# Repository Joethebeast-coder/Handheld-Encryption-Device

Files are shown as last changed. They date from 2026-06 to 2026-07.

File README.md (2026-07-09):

# Handcryption

A hardware-based encrypted peer-to-peer messaging device built on **CircuitPython** (ESP32-S2), with a companion Flask server for speech-to-text, message relay, and group chat support.

---
## Pre-funding Images
___
### Shell Top
IMG_E3014

### Shell Bottom
IMG_E3015

---
## Final Images
___
### Shell Top
IMG_E3039

### Shell Bottom


___
## Table of Contents

- [Overview](#overview)
- [Hardware](#hardware)
- [Project Structure](#project-structure)
- [How It Works](#how-it-works)
  - [Wi-Fi Setup](#wi-fi-setup)
  - [Server Connection & Authentication](#server-connection--authentication)
  - [Encryption (Cencrypt)](#encryption-cencrypt)
  - [Voice Message Encryption (RSA)](#voice-message-encryption-rsa)
  - [Peer-to-Peer Messaging](#peer-to-peer-messaging)
  - [Group Chat](#group-chat)
  - [Speech-to-Text](#speech-to-text)
  - [Text & Voice Input](#text--voice-input)
- [Server Setup](#server-setup)
- [Device Setup](#device-setup)
- [UI & Navigation](#ui--navigation)
- [File Storage](#file-storage)
- [Credits](#credits)

---

## Overview

### [Video Overview (Pre-funding)](https://www.youtube.com/watch?v=kqKA_LZ2jB4)
### [Full Build Test](https://youtu.be/IIfR6bDeaTY)

Handcryption is a hardware-based encrypted peer-to-peer messaging device built around physical ESP32-S2 devices and a Flask server hosted on a Raspberry Pi 4, exposed publicly via a **Cloudflare tunnel**. Messages can be sent as transcribed text or as fully encrypted voice clips. Text is transcribed by a local Vosk speech-to-text model on the companion server (or typed directly on the device), encrypted using a custom substitution cipher (text) or an RSA-protected XOR cipher (voice), and relayed through the server's mailbox system. The device uses an e-ink display and physical buttons for all interaction — no smartphone or touchscreen required.

Each device is assigned a unique numeric ID on first boot, which is used to route messages and identify contacts. A secondary group chat feature allows multiple devices to post to a shared encrypted channel viewable in a basic web interface.

> **Note on the platform:** This project originally targeted MicroPython. It now runs on **CircuitPython** (tested on CircuitPython 10.x for the Feather ESP32-S2). Display output uses Adafruit's `adafruit_epd` library rather than a standalone MicroPython driver, and several standard-library gaps in CircuitPython (e.g. `random.shuffle`, `os.path`) are worked around in the device code.

---

## Hardware

| Component | Purpose |
|---|---|
| Adafruit ESP32-S2 Feather (CircuitPython) | Main controller |
| Adafruit 2.13" SSD1680 monochrome e-ink display (250×122) | UI output via SPI |
| MAX17048 fuel gauge (I2C) | Battery percentage reading |
| DAC output | Audio feedback chimes and voice message playback (via amplifier) |
| Analog microphone (ADC) | Voice recording at 16 kHz |
| 6× push buttons | Record, Send, Select, Up, Down, Shut Off |

**Pin assignments:**

| Pin | Function |
|-----|---|
| 5 | Record button |
| 15 | Send message button |
| 39 | Select button |
| 8 | Up button |
| 38 | Down button |
| 16 | Shut-off button |
| A0 | Speaker (PWM, via amplifier) |
| A1 | Microphone (ADC) |
| 4/3 | I2C SCL/SDA (MAX17048) |
| 36/35/37 | SPI SCK/MOSI/MISO (e-ink) |
| 12/6/13/9 | E-ink DC/Busy/CS/Reset |

###



---

## Project Structure

```
handcryption/
├── code.py              # ESP32-S2 CircuitPython firmware (device code)
├── settings.toml        # Server URL + auth token (see Device Setup)
├── server.py            # Flask server (STT + relay + group chat backend)
├── Cencrypt.py          # Custom substitution cipher (cipher/decipher)
├── font5x8.bin          # Bitmap font used by adafruit_epd text rendering
├── lib/
│   ├── adafruit_epd/    # E-ink display library
│   ├── adafruit_requests/
│   ├── adafruit_connection_manager/
│   └── adafruit_framebuf/
├── models/
│   └── vosk-model-small-en-us-0.15/   # Vosk offline STT model (server-side)
├── templates/
│   └── web_msg.html     # Group chat web interface (server-side)
├── wifi.json            # Known Wi-Fi networks (auto-created)
├── known_ids.json       # Per-device-ID shuffled alphabet store (auto-created)
├── contacts.json        # Contact name → device ID map (auto-created)
├── history.json         # Message log, sent and received (auto-created)
├── my_letters.json      # Client-side cipher alphabet (auto-created)
├── gc_username.json     # Group chat username (auto-created)
├── priv_keys.json       # RSA key material for voice message encryption (auto-created)
└── device_ID.json       # This device's unique ID (auto-created on first boot)
```

> On CircuitPython, the main firmware file is named `code.py` on the device. The libraries under `lib/` come from the Adafruit CircuitPython library bundle.

---

## How It Works

### Wi-Fi Setup

On first boot (or if no known network is reachable), the device prompts the user to record a Wi-Fi name and password by voice. Since voice-to-text transcription of network credentials is error-prone, the device provides a character-by-character editor:

- **Up** — capitalize the current letter
- **Down** — lowercase the current letter
- **Select** — move to the next letter
- **Send** — toggle the current word between digit and word form (e.g., "five" ↔ "5"), useful for fixing numbers misheard as words

Once confirmed, the SSID/password pair is appended to a list in `wifi.json`. On every subsequent boot, the device tries each known network in order; if none connect within the timeout, it prompts for a new network and adds it to the list.

### Server Connection & Authentication

The device does not hardcode a server address. Instead, the server URL and a shared authentication token are read from `settings.toml`:

```
SERVER_URL = "https://your-endpoint.example.com"
DEVICE_TOKEN = "your-long-random-shared-secret"
```

All requests to the server include an `X-Auth` header carrying the token, and the Flask server rejects any request without the matching token (HTTP 401). This keeps the publicly reachable endpoint from being driven by anyone who discovers the URL.

Because the server is reached over an outbound tunnel, the device works from any network with internet access — the Raspberry Pi does not need port forwarding or a static public IP.

### Encryption (Cencrypt)

Handcryption uses [Cencrypt](https://pypi.org/project/Cencrypt/), a custom substitution cipher library available on PyPI, for text messages. The full printable character set (letters, digits, punctuation, space) is stored in `LETTERS`. When two devices connect for the first time, the sending device shuffles a copy of `LETTERS` and sends it to the recipient via the server mailbox as that device's personal cipher alphabet. This shuffled alphabet is saved to `known_ids.json` on the sender and `my_letters.json` on the recipient, so future sessions reuse the same key.

- `Cencrypt.cipher(message, alphabet)` — encrypts a plaintext string using the shuffled alphabet; returns the ciphertext and the key used for that message.
- `Cencrypt.decipher(ciphertext, alphabet)` — decrypts a message given the matching alphabet.

The combined message sent over the wire is `key + ciphertext` concatenated into a single string.

> **Note:** CircuitPython's `random` module has no `shuffle()`, so the device implements a Fisher–Yates shuffle internally to build cipher alphabets.

### Voice Message Encryption (RSA)

Voice messages use a separate encryption scheme since the substitution cipher only operates on text. Each device generates a 2048-bit RSA keypair on first boot (the server generates the large primes, since this is too slow on the microcontroller itself) and publishes its public key to the server. The public key is re-published on every boot, so a failed first-boot upload self-heals on the next start.

To send a voice message:
1. A random XOR key is generated locally.
2. The recorded PCM audio is XOR-encrypted with that key.
3. The XOR key itself is encrypted using the recipient's RSA public key (fetched from the server via `get_cont_pub_key`).
4. The encrypted key and encrypted audio are concatenated, base64-encoded, and sent through the mailbox with `"type": "audio"`.

On receipt, the recipient decrypts the XOR key using its own RSA private key, then XOR-decrypts the audio and plays it back through the speaker. If no public key is on file for the target contact, the device reports this instead of failing.

> **Note:** Audio messaging is the most fragile feature of the device. Because capture relies on a simple analog microphone (sampled directly through the ADC, with no dedicated audio codec or noise handling), recordings are prone to noise, clipping, and inconsistent levels. This affects both voice messages and speech-to-text accuracy. Text input (typed or transcribed) is the more reliable path; treat voice messages as best-effort.

### Peer-to-Peer Messaging

Messaging is relayed through the Flask server's mailbox system rather than direct socket connections. Each device has a unique 9-digit numeric ID assigned at first boot.

**Sending** (`esp_network_server`):
1. If the target device ID is new, prompts the user to name the contact (by voice or by typing), generates a shuffled cipher alphabet, and delivers it to the recipient via `POST /send-msg` with `"type": "key_exchange"`.
2. Saves the shuffled alphabet to `known_ids.json` keyed by the target's device ID. (Because JSON object keys are strings, device IDs are handled as strings for these lookups.)
3. For text messages: encrypts the outbound message using the stored alphabet for that contact and posts it with `"type": "txt"`.
4. For voice messages: encrypts the recorded audio using RSA as described above and posts it with `"type": "audio"`.
5. Saves the exchange to `history.json`.

**Receiving** (`esp_network_client`):
1. On entering receive mode, polls `GET /updates?Request=check_mail&dev_id=<id>` for new messages. Press **Record** to leave receive mode and return to the menu.
2. Messages are dispatched by type:
   - `"key_exchange"` — saves the received alphabet to `my_letters.json`.
   - `"txt"` — deciphers using the stored alphabet, plays a notification chime, displays the message, and logs it to `history.json`.
   - `"audio"` — decrypts the RSA-protected audio and plays it back.

### Group Chat

The group chat feature routes through the Flask server:

1. The user sets a username on first use (by voice or typing, persisted to `gc_username.json` so it only needs to be set once).
2. Messages are posted via `POST /gc` with the username, device ID, and message as parameters.
3. The server encrypts incoming messages with a single server-side shuffled alphabet (`ALPH`) and appends them to `messg_hist`.
4. Devices retrieve the server alphabet via `GET /updates?Request=serv_letters` and message history via `GET /updates?Request=prov_hist`, then decrypt locally with `Cencrypt.decipher`.
5. The web interface at `/gc` (served by `web_msg.html`) polls `GET /messages` every 2 seconds and renders the encrypted message log in a browser — messages appear encrypted to anyone intercepting the HTTP traffic.

### Speech-to-Text

Audio is captured at **16 kHz** mono using the ADC. While the record button is held, 16-bit PCM samples are collected in memory. On release, a WAV file is written to flash (`recording.wav`) and uploaded via `POST /stt` to the Flask server, along with the device's ID.

The server processes the audio with **Vosk** (offline STT, no cloud dependency) using `vosk-model-small-en-us-0.15`. The transcribed text is returned as JSON and displayed on screen for confirmation before use. A simple filler-word filter (`processing()`) strips common hesitation words (`"uh"`, `"um"`, `"hmm"`, etc.) from the result.

> The recording sample rate (16 kHz) matches the rate the Vosk model expects. Recording at a mismatched rate (e.g. 8 kHz) causes the server to reject the audio.

### Text & Voice Input

Anywhere the device asks for input — contact names, contact IDs, message text, and group chat — you can either **record by voice** or **type on the device**:

- At a record prompt, press **Up** to switch to the on-screen text editor instead of recording.
- In the text editor: **Up/Down** scroll through characters, **Select** commits the current character, **Record** (tap) is backspace, **Record** (hold ~1s) exits, and **Send** finishes.

This makes the device usable even when speech-to-text is unavailable or inaccurate.

---

## Server Setup

### Requirements

```bash
pip install flask waitress vosk Cencrypt pycryptodome
```

Download the Vosk model and place it at `models/vosk-model-small-en-us-0.15/`:
```
https://alphacephei.com/vosk/models
```

You will also need a way to expose the server publicly. This project uses a **Cloudflare tunnel** (`cloudflared`) running on the Raspberry Pi, which requires no port forwarding and works behind CGNAT.

### Authentication token

The server reads a shared secret from the `DEVICE_TOKEN` environment variable and rejects any request whose `X-Auth` header does not match. Set the same value here and in each device's `settings.toml`.

### Running

Run the Flask app under a production server (Waitress) so it survives long-running use:

```bash
DEVICE_TOKEN=your-long-random-shared-secret \
  waitress-serve --port=5000 server:app
```

In a separate terminal (or as a service), start the tunnel:

```bash
cloudflared tunnel --url http://localhost:5000
```

`cloudflared` prints a public HTTPS URL. Put that URL in each device's `settings.toml` as `SERVER_URL`. For a permanent address that survives restarts, use a **named** Cloudflare tunnel with your own domain instead of the quick-tunnel URL.

> For an always-on setup, run both the Flask server and `cloudflared` as `systemd` services so they restart on boot.

### Endpoints

All endpoints require the `X-Auth` header.

| Method | Route | Description |
|---|---|---|
| `POST` | `/stt` | Accepts a WAV file + device ID, returns `{"text": "..."}` |
| `GET` | `/messages` | Returns full encrypted group chat message history as JSON (polled by the web UI) |
| `GET/POST` | `/gc` | Post a group chat message or view the web UI |
| `GET/POST` | `/updates` | Returns server alphabet, group chat history, mailbox contents, RSA public keys, or stores a public key, depending on `Request` |
| `GET/POST` | `/getID` | Registers a new device ID; returns `"Clear"` if available or a new unique ID |
| `GET/POST` | `/send-msg` | Deposits a message (text, audio, or key exchange) into a device's mailbox by destination ID |
| `GET/POST` | `/get_prime` | Generates a 2048-bit RSA keypair's components for a requesting device |

---

## Device Setup

1. Flash **CircuitPython** to the ESP32-S2 Feather.
2. Copy the required libraries into `lib/` from the Adafruit CircuitPython library bundle: `adafruit_epd`, `adafruit_requests`, `adafruit_connection_manager`, and `adafruit_framebuf`. Also copy `font5x8.bin` to the drive root (used for text rendering).
3. Upload `code.py` (the device firmware), `Cencrypt.py`, and the `settings.toml` file to the device. `Cencrypt.py` can be downloaded from [PyPI](https://pypi.org/project/Cencrypt/).
4. Edit `settings.toml` with your server URL and token:
   ```
   SERVER_URL = "https://your-endpoint.example.com"
   DEVICE_TOKEN = "your-long-random-shared-secret"
   ```
5. Power on — on first boot, the device will prompt you to record or type a Wi-Fi network name and password (see [Wi-Fi Setup](#wi-fi-setup)).
6. After connecting, the device displays "HANDCRYPTION", plays the startup chime, registers its device ID with the server, generates its RSA keypair for voice messages, and publishes its public key.

---

## UI & Navigation

The main menu has four icon options navigated with **Up/Down** and confirmed with **Select**. The currently highlighted option is drawn with a border box.

| Icon | Option | Action |
|---|---|---|
| History | `0` | Browse past messages (sent and received) |
| Contacts | `1` | View or add contacts |
| Settings | `2` | Reset data or adjust volume |
| Message bubble | `3` | Access group chat |
| *(Send button)* | `4` | Send a direct message — choose text or voice |
| *(Idle timeout)* | `5` | Enter receive mode |

When sending a direct message (`4`), the device asks whether to send as **text** (Up) or **voice** (Down). Text messages go through the record-or-type → (transcribe) → confirm flow. Voice messages are recorded, encrypted with the recipient's RSA public key, and sent as raw encrypted audio without transcription.

**Button reference:**

| Button | Role |
|---|---|
| Record | Capture audio (hold); in the text editor, tap = backspace, hold = exit; also "go back" in some screens |
| Send | Open send-message flow / confirm in text editor |
| Select | Confirm selection / commit character in text editor |
| Up / Down | Navigate menus and characters; Up also switches a record prompt to typing |
| Shut Off (hold 1s+) | Deep sleep (wakes on next power press) |

**Display note:** The e-ink panel performs full refreshes only. The UI is designed to refresh once per screen change rather than continuously, so navigation updates when a selection changes rather than animating.

**Battery** is drawn as a small icon in the top-right corner of every screen. The device shows a charging prompt if battery drops below 45% and blocks until it reaches 60%.

**Audio feedback chimes:**
- `wake_chime` — on screen wake
- `handcryption_chime` — on startup
- `notif_chime` — on message received
- `shut_off_chime` — on entering deep sleep

---

## File Storage

All JSON files are created automatically on first boot if absent.

| File | Contents |
|---|---|
| `settings.toml` | `SERVER_URL` and `DEVICE_TOKEN` (server address + auth secret) |
| `wifi.json` | Array of known Wi-Fi networks as `[ssid, password]` pairs, tried in order on boot |
| `device_ID.json` | This device's unique 9-digit ID, registered with the server on first boot |
| `gc_username.json` | The username used for group chat, set on first use of that feature |
| `priv_keys.json` | RSA key material (`phi/d/n/key1/key2`) used for encrypting/decrypting voice messages |
| `known_ids.json` | `{ "device_id": [shuffled alphabet array], ... }` (keys stored as strings) |
| `contacts.json` | `{ "Name": "device_id", ... }` |
| `history.json` | Array of message records; sent entries carry a `To` field, received entries carry a `From` field |
| `my_letters.json` | Cipher alphabet received from sender (used in receive mode) |
| `recording.wav` | Temporary audio file, overwritten on each recording |

The **Settings → Reset** option wipes `contacts.json`, `history.json`, and `known_ids.json` back to empty — forcing a full re-handshake and new cipher key exchange on the next connection.

---

## Credits

This project began as a MicroPython build and was ported to **CircuitPython**. The e-ink display now uses Adafruit's [`adafruit_epd`](https://github.com/adafruit/Adafruit_CircuitPython_EPD) library.

The original MicroPython SSD1680 display driver and font work that inspired the earlier version of this project were based on work by [hfwang132](https://github.com/hfwang132), available at [hfwang132/ssd1680-micropython-drivers](https://github.com/hfwang132/ssd1680-micropython-drivers/tree/main). Many thanks for the MicroPython driver that made the display portion of the original project possible.

## AI Usage

AI was used to help find and fix bugs in the code, mainly when I converted the project from MicroPython to CircuitPython.

---

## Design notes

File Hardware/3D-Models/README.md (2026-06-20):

This is the folder for all 3D-Models. Note that many of the part measurements for height are estimates. The assembly does not show the standoffs and screws.

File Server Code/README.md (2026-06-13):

Quick Overview
---------------------------------------------------------
This is the server code that will run on a Raspberry Pi 4

How it works
----------------------------------------------------------------
It uses Flask to create an HTTP server where the microcontroller
can make requests.

Types of Requests
    1. Speech-to-text
        The microcontroller cannot run the speech-to-text API on its own, so it makes
        a request to the server to convert an audio file.
    2. Group Chat
        The microcontroller can connect to a group chat that is between every user. This
        section allows the microcontroller to send messages in the group chat
    3. Updates
        The microcontroller can request updates from the server, such as the server's set of letters
        used to encrypt the messages of the group chat, as well as its message history.

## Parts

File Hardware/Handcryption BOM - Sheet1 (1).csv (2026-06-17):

Item | ID | Quantity | Cost | Total Item Cost | Vendor
Adafruit 2.13" Monochrome eInk / ePaper Display with SRAM - 250x122 Monochrome with SSD1680 | 4197 | 2 | $22.50 | $45.00 | Adafruit
Tactile Button switch (6mm) x 20 pack | 367 | 1 | $2.50 | $2.50 | Adafruit
Adafruit ESP32-S2 Feather - 4 MB Flash + 2 MB PSRAM - STEMMA QT / Qwiic | 5000 | 2 | $17.50 | $35.00 | Adafruit | Total | $128.94
Lithium Ion Polymer Battery - 3.7v 100mAh | 1570 | 2 | $11.90 | $23.80 | Adafruit
6 Pieces Electret Microphone Amplifier Module MAX4466 Adjustable Gain | B08N4FNFTR | 1 | $9.99 | $9.99 | Amazon
Adafruit STEMMA Speaker - Plug and Play Audio Amplifier - JST PH 2mm | 3885 | 2 | $5.95 | $11.90 | Adafruit
JST PH 2mm 3-pin Plug-Plug Cable - 100mm long | 4336 | 1 | $0.75 | $0.75 | Adafruit
 |  |  |  | $0.00
 |  |  |  | $0.00
 |  |  |  | $0.00
 |  |  |  | $0.00
 |  |  |  | $0.00
 |  |  |  | $0.00
 |  |  |  | $0.00
 |  |  |  | $0.00
 |  |  |  | $0.00
 |  |  |  | $0.00
 |  |  |  | $0.00
 |  |  |  | $0.00
 |  |  |  | $0.00
 |  |  |  | $0.00
 |  |  |  | $0.00
 |  |  |  | $0.00
 |  |  |  | $0.00
 |  |  |  | $0.00
 |  |  |  | $0.00
 |  |  |  | $0.00
 |  |  |  | $0.00
 |  |  |  | $0.00
 |  |  |  | $0.00
 |  |  |  | $0.00
 |  |  |  | $0.00
 |  |  |  | $0.00
 |  |  |  | $0.00
 |  |  |  | $0.00
 |  |  |  | $0.00
 |  |  |  | $0.00
 |  |  |  | $0.00
 |  |  |  | $0.00
 |  |  |  | $0.00
 |  |  |  | $0.00
 |  |  |  | $0.00
 |  |  |  | $0.00
 |  |  |  | $0.00
 |  |  |  | $0.00
 |  |  |  | $0.00
 |  |  |  | $0.00
 |  |  |  | $0.00
 |  |  |  | $0.00
 |  |  |  | $0.00
 |  |  |  | $0.00
 |  |  |  | $0.00
 |  |  |  | $0.00
 |  |  |  | $0.00
 |  |  |  | $0.00
 |  |  |  | $0.00
 |  |  |  | $0.00
 |  |  |  | $0.00
 |  |  |  | $0.00
 |  |  |  | $0.00
 |  |  |  | $0.00
 |  |  |  | $0.00
 |  |  |  | $0.00
 |  |  |  | $0.00
 |  |  |  | $0.00
 |  |  |  | $0.00
 |  |  |  | $0.00
 |  |  |  | $0.00
 |  |  |  | $0.00
 |  |  |  | $0.00
 |  |  |  | $0.00
 |  |  |  | $0.00
 |  |  |  | $0.00
 |  |  |  | $0.00
 |  |  |  | $0.00
 |  |  |  | $0.00
 |  |  |  | $0.00
 |  |  |  | $0.00
 |  |  |  | $0.00
 |  |  |  | $0.00
 |  |  |  | $0.00
 |  |  |  | $0.00
 |  |  |  | $0.00
 |  |  |  | $0.00
 |  |  |  | $0.00
 |  |  |  | $0.00
 |  |  |  | $0.00
 |  |  |  | $0.00
 |  |  |  | $0.00
 |  |  |  | $0.00
 |  |  |  | $0.00
 |  |  |  | $0.00
 |  |  |  | $0.00
 |  |  |  | $0.00
 |  |  |  | $0.00
 |  |  |  | $0.00
 |  |  |  | $0.00
 |  |  |  | $0.00
 |  |  |  | $0.00
 |  |  |  | $0.00
 |  |  |  | $0.00
 |  |  |  | $0.00
 |  |  |  | $0.00
 |  |  |  | $0.00
 |  |  |  | $0.00
 |  |  |  | $0.00
 |  |  |  | $0.00
 |  |  |  | $0.00
 |  |  |  | $0.00
 |  |  |  | $0.00
 |  |  |  | $0.00
 |  |  |  | $0.00
 |  |  |  | $0.00
 |  |  |  | $0.00
 |  |  |  | $0.00
 |  |  |  | $0.00
 |  |  |  | $0.00
 |  |  |  | $0.00
 |  |  |  | $0.00
 |  |  |  | $0.00
 |  |  |  | $0.00
 |  |  |  | $0.00
 |  |  |  | $0.00
 |  |  |  | $0.00
 |  |  |  | $0.00
 |  |  |  | $0.00
 |  |  |  | $0.00
 |  |  |  | $0.00
 |  |  |  | $0.00
 |  |  |  | $0.00
 |  |  |  | $0.00
 |  |  |  | $0.00
 |  |  |  | $0.00
 |  |  |  | $0.00
 |  |  |  | $0.00
 |  |  |  | $0.00
 |  |  |  | $0.00
 |  |  |  | $0.00
 |  |  |  | $0.00
 |  |  |  | $0.00
 |  |  |  | $0.00
 |  |  |  | $0.00
 |  |  |  | $0.00
 |  |  |  | $0.00
 |  |  |  | $0.00
 |  |  |  | $0.00
 |  |  |  | $0.00
 |  |  |  | $0.00
 |  |  |  | $0.00
 |  |  |  | $0.00
 |  |  |  | $0.00
 |  |  |  | $0.00
 |  |  |  | $0.00
 |  |  |  | $0.00
 |  |  |  | $0.00
 |  |  |  | $0.00
 |  |  |  | $0.00
 |  |  |  | $0.00
 |  |  |  | $0.00
 |  |  |  | $0.00
 |  |  |  | $0.00
 |  |  |  | $0.00
 |  |  |  | $0.00
 |  |  |  | $0.00
 |  |  |  | $0.00
 |  |  |  | $0.00
 |  |  |  | $0.00
 |  |  |  | $0.00
 |  |  |  | $0.00
 |  |  |  | $0.00
 |  |  |  | $0.00
 |  |  |  | $0.00
 |  |  |  | $0.00
 |  |  |  | $0.00
 |  |  |  | $0.00
 |  |  |  | $0.00
 |  |  |  | $0.00
 |  |  |  | $0.00
 |  |  |  | $0.00
 |  |  |  | $0.00
 |  |  |  | $0.00
 |  |  |  | $0.00
 |  |  |  | $0.00

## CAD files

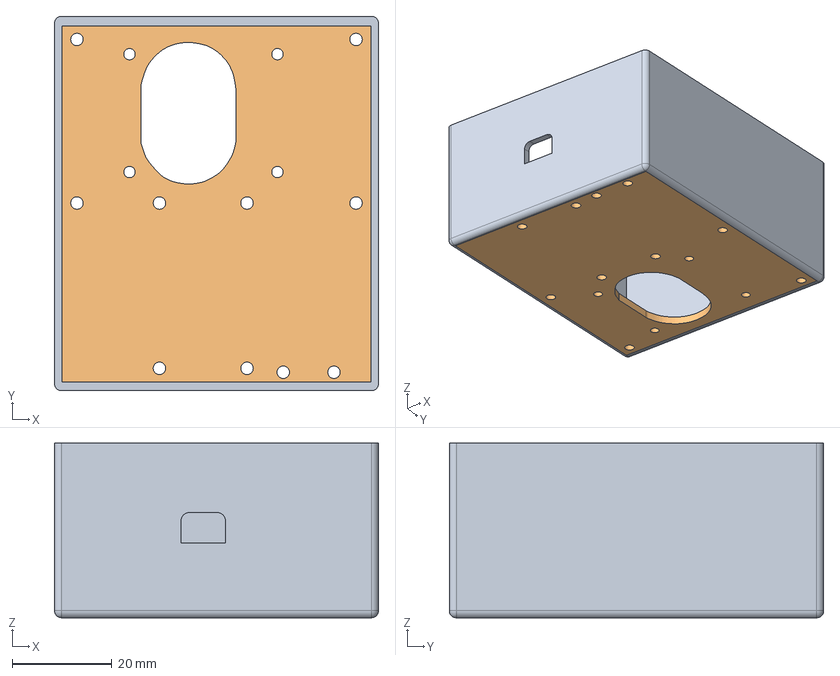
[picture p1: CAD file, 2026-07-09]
Hardware/3D-Models/Main Body.step
65.0 x 75.1 x 35.0 mm

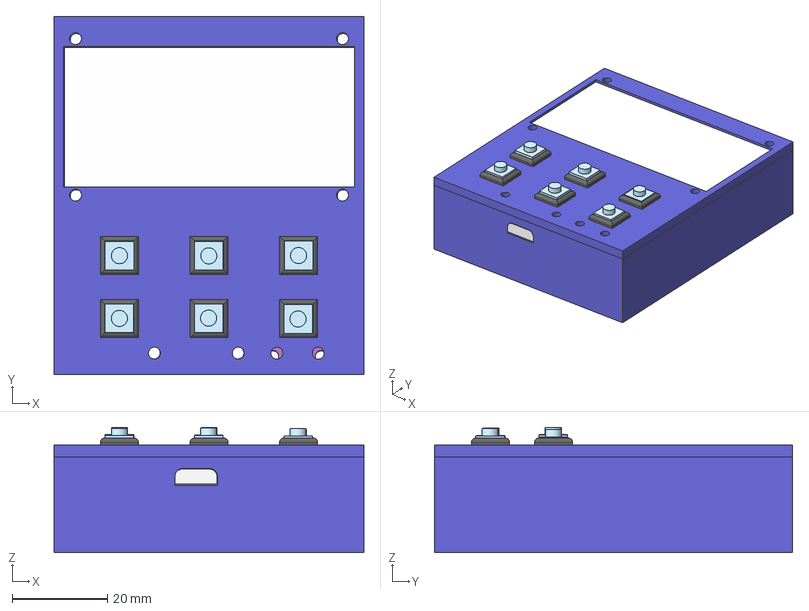
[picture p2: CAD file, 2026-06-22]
Hardware/3D-Models/Assembly 1.step
65.0 x 75.1 x 26.3 mm

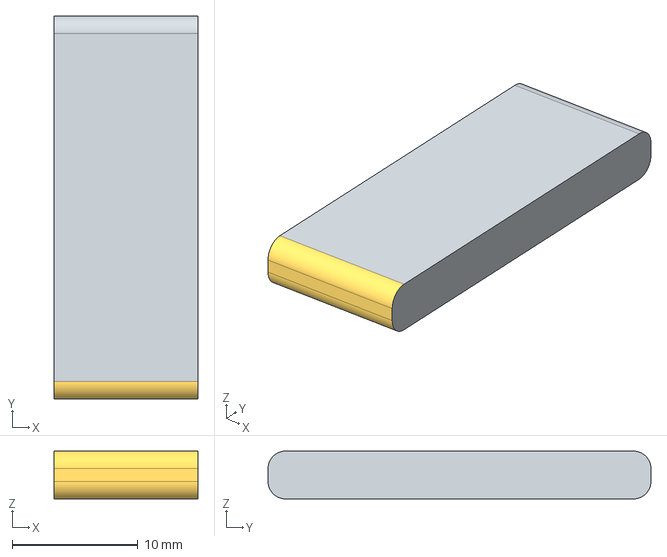
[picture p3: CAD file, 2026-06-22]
Hardware/3D-Models/Battery.step
11.4 x 30.5 x 3.81 mm

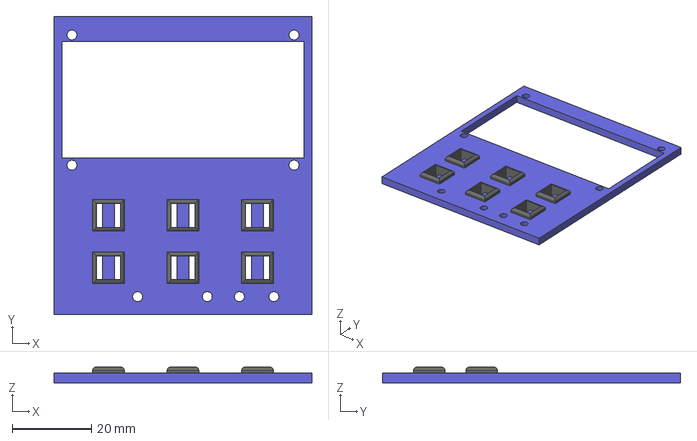
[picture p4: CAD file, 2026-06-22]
Hardware/3D-Models/Top Cover.step
65.0 x 75.1 x 4.00 mm

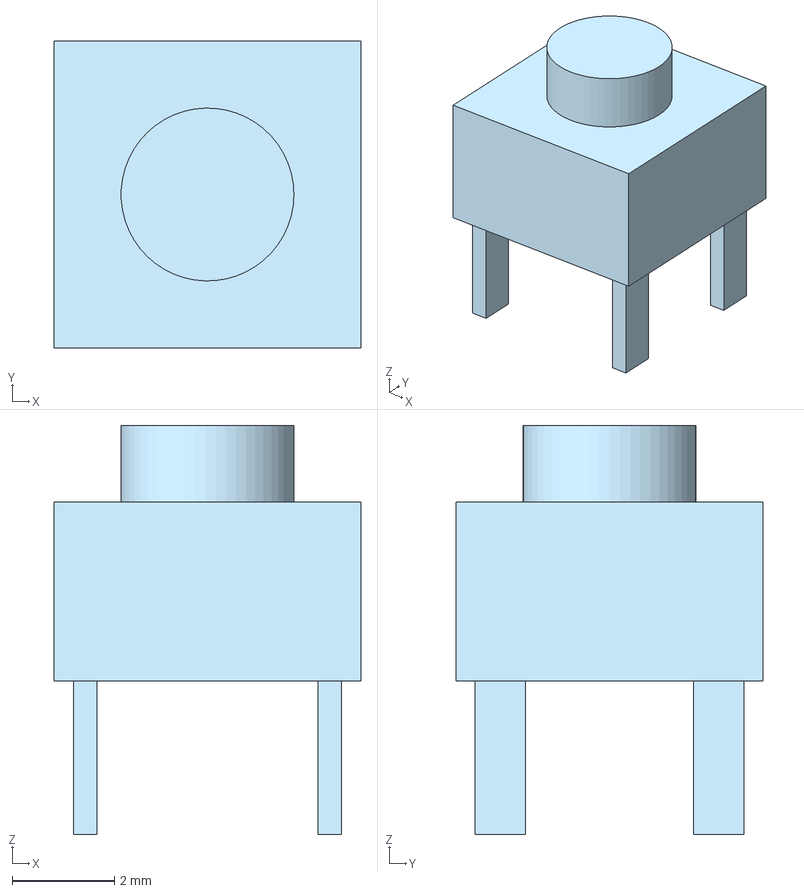
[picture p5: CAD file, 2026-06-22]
Hardware/3D-Models/Button.step
6.00 x 6.00 x 8.00 mm

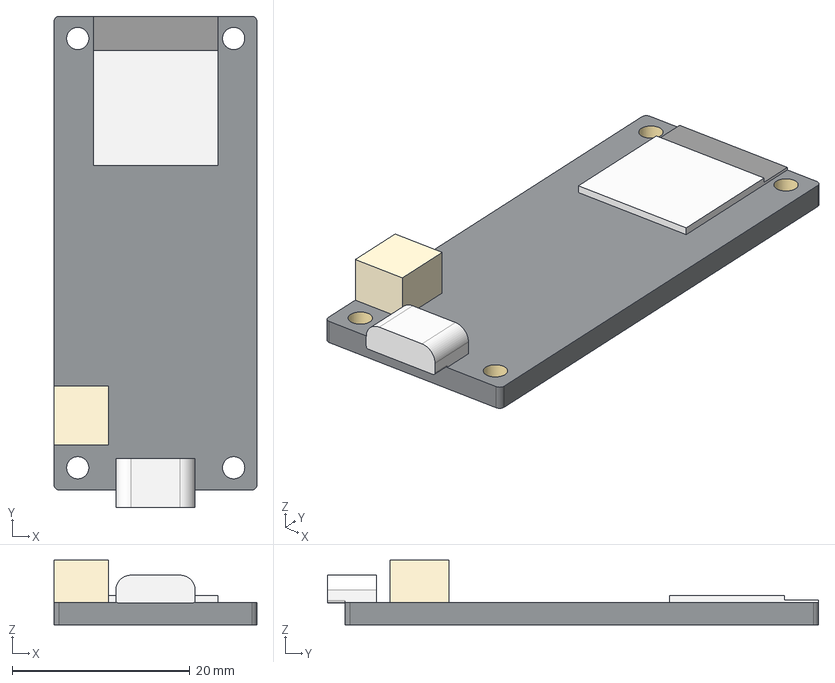
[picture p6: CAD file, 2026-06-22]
Hardware/3D-Models/Adafruit ESP32-S2 Feather Board.step
22.9 x 55.3 x 7.30 mm

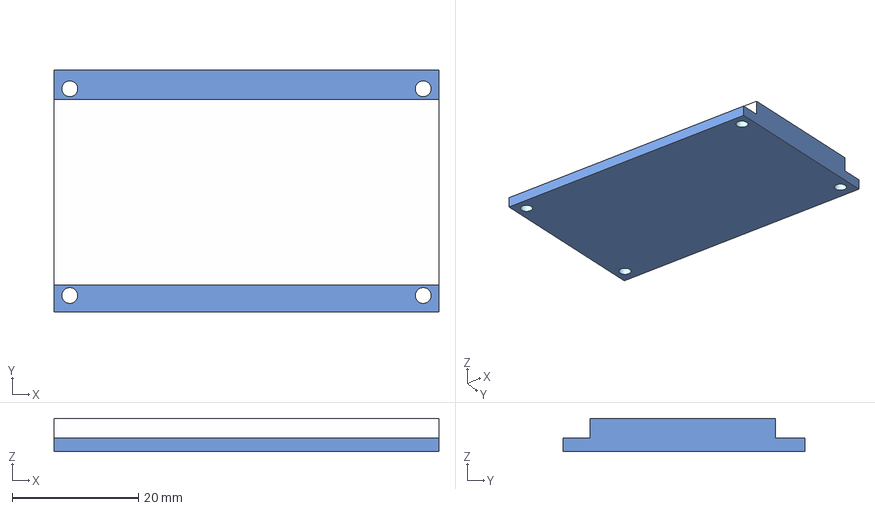
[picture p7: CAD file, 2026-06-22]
Hardware/3D-Models/Adafruit 2.13- Monochrome eInk - ePaper Display.step
61.0 x 38.3 x 5.30 mm

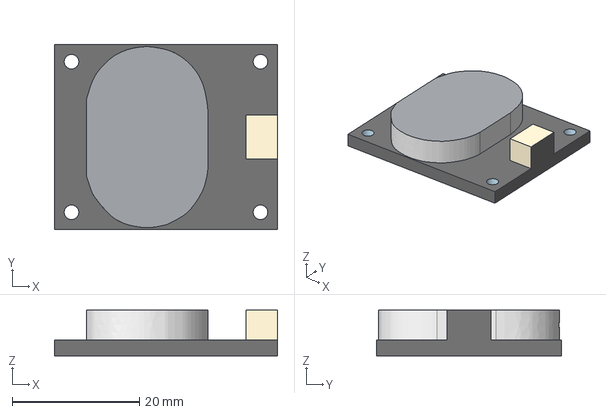
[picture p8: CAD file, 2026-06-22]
Hardware/3D-Models/Adafruit STEMMA Speaker.step
35.0 x 29.0 x 7.20 mm

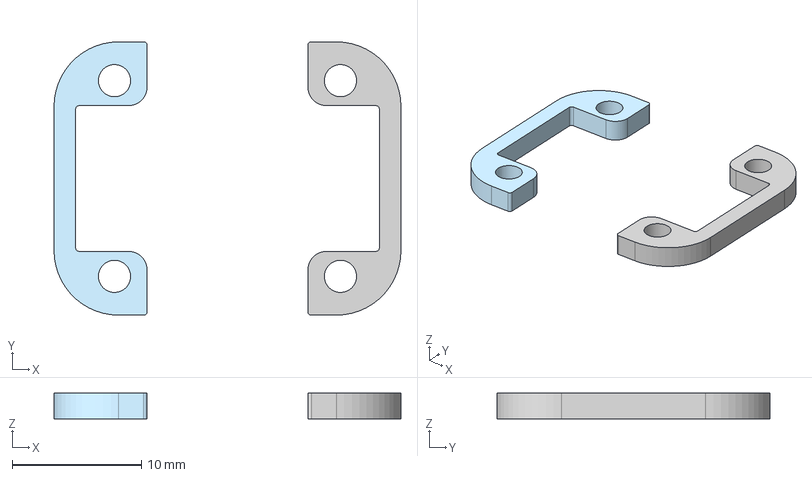
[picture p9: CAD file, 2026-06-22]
Hardware/3D-Models/Board Holders.step
26.8 x 21.1 x 2.00 mm

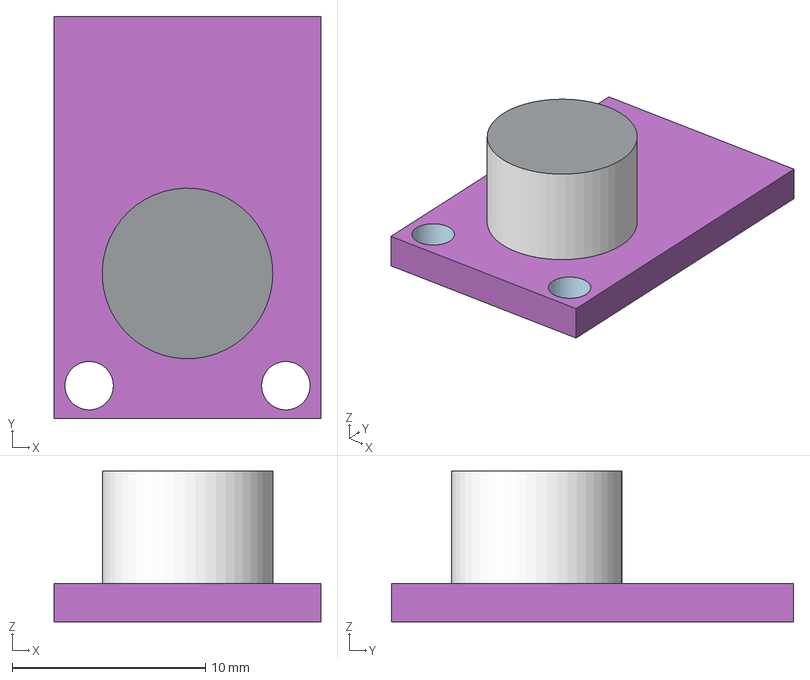
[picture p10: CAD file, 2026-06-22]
Hardware/3D-Models/Electret Microphone Amplifier Module MAX4466.step
13.8 x 20.8 x 7.80 mm

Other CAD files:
Hardware/3D-Models/Main Body (3).stl
Hardware/3D-Models/Adafruit 2.13- Monochrome eInk - ePaper Display.stl
Hardware/3D-Models/Adafruit ESP32-S2 Feather Board.stl
Hardware/3D-Models/Adafruit STEMMA Speaker.stl
Hardware/3D-Models/Assembly 1.stl
Hardware/3D-Models/Battery.stl
Hardware/3D-Models/Board Holders.stl
Hardware/3D-Models/Button.stl
Hardware/3D-Models/Electret Microphone Amplifier Module MAX4466.stl
Hardware/3D-Models/Top Cover.stl

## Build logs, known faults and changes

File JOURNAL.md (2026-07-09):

# Logs

## Hancryption Status Update 0.0.1
---------------------------------------
I have created the basic logic framework for the speech-to-text with processing. I am currently using many placeholders, however. Will be updating that by 0.0.4 at the latest. For encryption, I am using my previously developed “Cencrypt” Python library.
_____
### What’s Next in 0.0.2?
___
- Networking Framework
- Encryption Setup



#

## Handcryption Status Update 0.0.1.5
---
### What’s New?
____
I created a rough sketch of the device. I also wrote down a tentative list of parts I would need. See Below
0.0.2 Should be released by 6/4/26.
___
*Note: I completely forgot about the screen and the parts needed for that.
E-ink display
6 buttons



#

## Hancryption Status Update 0.0.2
---
### What Happened?
___
I added classes for server and client communication so the device could be either. I also added the encryption feature, which generates a unique key for each known IP address. The network also includes a client status check that occurs every 15 seconds, in which the client sends its IP address to the server.
___
### What’s Next in 0.0.3?
___
- Full draft code for a device. This will include all of the machine programming for the ESP32 chip, which is for the microphone, eink screen, and buttons.

- By 0.0.2.3, a draft parts list should be complete.

- By 0.0.2.5, a wiring diagram should be complete.



#

## Hancryption Status Update 0.0.2.1
---
### What Happened?
___
I patched some bugs in the client class so I could add a main loop for the device. When the device is sending, it is the server, and in any other circumstance, it is the client, it is idle and waiting for a message.
I added the button and microphone logic for the specific components.
I need to add the logic for the eink display



#

## Hancryption Status Update 0.0.3 (Combined)
______________________________________________
### What Happened in 0.0.2.3?
__________________________________________________________
I have created a parts list for this project:
Adafruit:
  - Adafruit Electret Microphone Amplifier - MAX4466 
              with Adjustable Gain
  - Adafruit 2.13" Monochrome eInk / ePaper Display 
              with SRAM - 250x122 Monochrome with SSD1680
  - Adafruit ESP32-S2 Feather - 4 MB Flash + 2 MB 
              PSRAM - STEMMA QT / Qwiic
  - Lithium Ion Polymer Battery - 3.7v 100mAh
  - Tactile Button switch (6mm) x 20 pack
  - Small Enclosed Piezo w/Wires
###
I have decided to use the Adafruit ESP32-S2 Feather as my microcontroller, as it takes care of the LiPoly battery charging, so I don't have to buy extra parts for it. I can also charge the battery through the USB-C on the board. It also has many GPIO pins that I can give to my e-Ink display, as well as the switches (6).
__________________________________________________________
### What Happened in 0.0.2.5?
__________________________________________________________
I created a wiring diagram for the components listed in the parts list. The time-lapse can be seen on Lapse*.

*I forgot to add the piezo in the time-lapse, and I wired the SDA and SCL pins to buttons, which was not supposed to happen, so later, I added the piezo, and moved the button wires to spare analog pins. You can see these in the screenshot below.
__________________________________________________________
### What Happened in 0.0.3?
__________________________________________________________
I made a complete draft of the code for the device. I added all of the button logic and basic e-ink display code. I added a loading screen with "HANCRYPTION" in block text and a sleep screen. To "power down", when the user holds the power button for more than 1 second, it goes into deep-sleep, which is basically off for microcontrollers. If it is less than that, it just goes idle. Of course, this is not the final code. I will keep adding more and more features that are compatible with the current set of parts I already have.
__________________________________________________________
### What's Next in 0.0.4?
__________________________________________________________
-Extra UI Features
-Possibility of Games




#

## Handcryption Status Update 0.0.3.2 (Big News)
________________________________________________
### What Happened?
__________________________________________________________________________________
So, I was able to add in a UI that includes settings, contacts, message history, as well as battery status. In the settings, the user can change the volume of the piezo, as well as clear the files on their device (Contacts, Known IPs, and Message History. When hovering over a choice, the icon (the volume icon, for example) repeatedly switches from inverted to normal.
________________________________________________________________________________
However, while I was debugging, I found a MAJOR problem. My measly ESP32 microcontroller doesn't have enough CPU and RAM to run the speech-to-text model. However, I can pivot from this by using the VOSK model paired with my Raspberry Pi 4 that I have on hand as a server to run the model for the microcontroller. This opens up a whole new possibility. We can now have a main hub that monitors the devices, serves the speech-to-text requests, and sends the text back.
________________________________________________________________________________
### What's Next?
  - Speech-to-text code for the Raspberry Pi
  - Communication Protocol between the device and Pi



#

## Handcryption Status Update 0.0.3.5
_____________________________________
### What Happened?
_____________________________________________________
I was able to set up a server on my Raspberry Pi 4 with the help of Copilot (I do not know Flask in the slightest). So now, when a device wants to send a message, the audio recording is sent to the Pi, requesting that it be translated to text. I've been experimenting with Claude on making a website to monitor the server's status, but I will talk about that more in a later update if I decide to go that route. 
__________________________________________________________
Today, I was able to make a CAD model of the housing of the device (The process of which is posted on Lapse). I have to admit, it looks a lot like the phreakers from the early days of calling. 
__________________________________________________________
### What's Next?
  - Decision on whether to pursue web monitoring
  - Preliminary BOM
  - Timeline Estimation
  - Extra Features for the Device



#

## Handcryption Status Update 0.0.3.6
_____________________________________
### What Happened?
__________________________________________________________
I added a cool new feature to the Handcryption device-GROUP CHATS!! This allows every user with a Handcryption device who opts to join the group to participate in conversations, fostering a more connected experience among users. I learned how to use Flask (thanks to GeeksforGeeks), which enabled me to seamlessly integrate the group chat feature into the server code running on the Raspberry Pi. 
__________________________________________________________
In addition to the chat functionality, there is now a website hosted on the Raspberry Pi's IP address that displays all the messages in the group chat. The caveat is that every message on the website is shown in its encrypted form to maintain security and confidentiality. 

__________________________________________________________
Looking ahead, I plan to implement a feature that would allow Handcryption users to sign in to the website. This will enable them to view messages in a decrypted format, enhancing user experience while still prioritizing privacy. I believe these developments will significantly improve user engagement and create a more dynamic platform for communication.

     My device(s) are becoming more and more like a phone

__________________________________________________________
### What's next?
__________________________________________________________
  - Preliminary BOM
  - Increase Website Functionality
  - Timeline Estimation
  - Code Cleanup and Extra Features
___
Photo Description: Some of the server code for the group chat


# 

## Handcryption Status Update 0.0.3.9
_____________________________________
## What Happened?
__________________________________________________________
Ok, big change to the workings of this device. Previously, this device could only work locally, but through my Raspberry Pi server and a domain through ngrok, I can make the device work on the cloud, and I have altered the server code and main device code to work this way. 
__________________________________________________________
Also, instead of using IPs to identify devices, I am using my own identification system that is like a phone number, a sequence of 9 digits. I recognize that this may be a small number of available sequences, but for now, it is a good amount. I can change this later.
__________________________________________________________
So, to send messages now, instead of using a socket, the device sends an HTTP request to the ngrok domain hosted by the Pi. The request includes the message, the destination's ID, and the sender's (the device's) ID. The server then stores this information in a "mailbox" -a collection of all sent messages. The receiving device, every 2 seconds, is sending an HTTP request to the server asking if there is anything in its mailbox. If so, the server returns the message(s) with the sender ID so the receiver can match that to a contact. 
__________________________________________________________
The cloud update has made my overall code length shorter, as most of the long sequences of code have been simplified to shorter HTTP requests.
__________________________________________________________
Also, as promised, this is my part BOM: https://github.com/Joethebeast-coder/Handheld-Encryption-Device/tree/main/Hardware
__________________________________________________________
## What's Next in 0.0.4?
__________________________________________________________
  - Extra Add-on Device Features
  - Maybe more website interactivity



#

## Hancryption Status Update 0.0.4
____________________________________
### What Happened?
__________________________________________________________
So, I added in one last new feature to my code: voice messages. In order to play the audio, I have decided to ditch the piezo and use an actual speaker breakout, and I have updated the BOM on my Github as such (check the last devlog). 
__________________________________________________________
Other than that, I have been cleaning and debugging the code, and adding in comments; all to get it ready to request for funding. For some reason, my hackatime on the Stardance website isn't synced with what my Hackatime dashboard says. So, I'm posting this much eariler than I would have wanted in hopes to fix that issue.
__________________________________________________________
## What's Next?
- Sneak Peek at Funding Request Version
- Timeline



#

## Handcryption Status Update 0.1
___________________________________
### What's Happening?
__________________________________________________________
So, I have been able to clean up everything in my code. I have added comments and the ability to connect to Wi-Fi. All of my code has been uploaded to GitHub for review for funding.
__________________________________________________________
Also on GitHub are my 3D models. Be aware that the part models' heights are an estimate based on the total height of the part given (if that makes sense). When printing the cover, I am planning to swap the filament from PLA to TPU to make the pads holding the buttons squishy.
__________________________________________________________
I am a little disappointed that the hackatime in my VS Code editor stopped recording time, and I lost 2 hours, but I will just use Lapse from now on. 
__________________________________________________________



#

## Handcryption Status Update 0.2
___
### Elephants in the Room
___
Ok, It's been a while; I've been doing a lot of work without logging time. But I have been able to assemble a device. The sad part is, one screen was defective, so I was only able to make one, but in the future I will finish the second one. The biggest change is that I've changed my code from MicroPython to CircuitPython for convenience. I have also increased the height of the main body because I am now using terminal blocks, which add height. 
___
I have submitted this project for review, and I really hope this is finally the moment I've been waiting for for so long.

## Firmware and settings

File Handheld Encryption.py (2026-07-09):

import os
import time
import math
import random
import binascii

def shuffle_in_place(seq):
    # CircuitPython's random module has no shuffle(); implement Fisher-Yates.
    for i in range(len(seq) - 1, 0, -1):
        j = random.randint(0, i)
        seq[i], seq[j] = seq[j], seq[i]
    return seq

import json
import board
import digitalio
import busio
import analogio
import pwmio
import displayio
import wifi
import socketpool
import ssl
import adafruit_requests as requests
from fourwire import FourWire
from adafruit_display_text import label
import terminalio
import busio
import digitalio
from adafruit_epd.ssd1680 import Adafruit_SSD1680
from adafruit_epd.epd import Adafruit_EPD

BASE_URL = os.getenv("SERVER_URL")
DEVICE_TOKEN = os.getenv("DEVICE_TOKEN")

# Map MicroPython timing and json module names to their standard names
utime = time
ujson = json

def file_exists(filename):
    try:
        os.stat(filename)
        return True
    except OSError:
        return False
    
# Keep your custom encryption logic intact
import Cencrypt as ce

# Helper to automatically translate integer pin numbers to your board's pins
def get_board_pin(pin_num):
    pin_obj = getattr(board, f"D{pin_num}", None)
    if pin_obj is None:
        pin_obj = getattr(board, f"A{pin_num}", None)
    return pin_obj

# ____________________________ Pin & Button Compatibility Wrapper ____________________________
class PinWrapper:
    IN = "in"
    PULL_UP = "pull_up"
    OUT = "out"
    
    def __init__(self, pin_num, direction=None, pull=None):
        pin_obj = get_board_pin(pin_num)
        if pin_obj is None:
            raise ValueError(f"Pin {pin_num} could not be mapped to your board layout.")
            
        self._raw_pin = pin_obj      # kept for deep-sleep PinAlarm
        self._pull_up = (pull == PinWrapper.PULL_UP)
        self.pin = digitalio.DigitalInOut(pin_obj)
        if direction == PinWrapper.OUT:
            self.pin.direction = digitalio.Direction.OUTPUT
        else:
            self.pin.direction = digitalio.Direction.INPUT
            if pull == PinWrapper.PULL_UP:
                self.pin.pull = digitalio.Pull.UP

    def release(self):
        # Free the pin so alarm.pin.PinAlarm can use it for deep sleep.
        try:
            self.pin.deinit()
        except Exception:
            pass
                
    def value(self, val=None):
        if val is not None:
            self.pin.value = bool(val)
            return
        # Active-low buttons: pressed returns 0, unpressed returns 1 to match MicroPython
        return 0 if not self.pin.value else 1

# Overwrite the Pin call to use our compatibility wrapper
Pin = PinWrapper

# Instantiates buttons exactly as named in your original codebase
record_button = Pin(5, Pin.IN, Pin.PULL_UP) 
send_mes_button = Pin(15, Pin.IN, Pin.PULL_UP)
select_button = Pin(39, Pin.IN, Pin.PULL_UP)
up = Pin(8, Pin.IN, Pin.PULL_UP)
down = Pin(38, Pin.IN, Pin.PULL_UP)
shut_off = Pin(16, Pin.IN, Pin.PULL_UP)

# ____________________________________ Voltage Sensing ____________________________________
MAX17048_ADDR = 0x36
i2c_bus = busio.I2C(get_board_pin(4), get_board_pin(3))  

def read_register(reg):
    while not i2c_bus.try_lock():
        pass
    try:
        buffer = bytearray(2)
        i2c_bus.writeto_then_readfrom(MAX17048_ADDR, bytes([reg]), buffer)
        return (buffer[0] << 8) | buffer[1]
    finally:
        i2c_bus.unlock()

def get_percent():
    raw = read_register(0x04)
    return raw / 256

def draw_battery(epd_obj, percent, x, y): 
    percent = max(0, min(100, percent))
    width = 30
    height = 12
    nub_width = 3

    epd_obj.draw_rectangle(x, y, x + width, y + height)
    epd_obj.draw_rectangle(x + width, y + 3, x + width + nub_width, y + height - 3)

    fill_width = int((width - 4) * (percent / 100))
    for fy in range(y + 2, y + height - 1):
        epd_obj.draw_line(x + 2, fy, x + 2 + fill_width, fy)

# ______________________________________ Piezo Setup ______________________________________
# Hardware PWM removes heavy CPU math and microsecond-loop lagging
pwm_speaker = pwmio.PWMOut(board.A0, frequency=30000, duty_cycle=0, variable_frequency=True)

def play_tone(frequency, percent_vol=1, duration=0.3, sample_rate=8000): 
    pwm_speaker.frequency = int(frequency)
    # A 50% duty cycle (32768) represents maximum square wave volume
    pwm_speaker.duty_cycle = int(32768 * max(0, min(1, percent_vol)))
    time.sleep(duration)
    pwm_speaker.duty_cycle = 0

def notif_chime(percent_vol=1):
    play_tone(3000, percent_vol, 0.3)
    play_tone(2000, percent_vol, 0.3)
    play_tone(1000, percent_vol, 0.3)
    play_tone(3000, percent_vol, 0.3)

def handcryption_chime(percent_vol=1):
    tones = [(1800, 0.18), (1400, 0.15), (900, 0.12), (1600, 0.15), (2200, 0.20), (2600, 0.10)]
    for freq, duration in tones:
        play_tone(freq, percent_vol, duration)

def wake_chime(percent_vol=1):
    play_tone(1500, percent_vol, 0.15)
    play_tone(3000, percent_vol, 0.3)

def shut_off_chime(percent_vol=1):
    play_tone(3000, percent_vol, 0.15)
    play_tone(2000, percent_vol, 0.15)
    play_tone(1000, percent_vol, 0.15)

# ______________________________________ E-ink Setup ______________________________________
displayio.release_displays()

class Color:
    WHITE = 1
    BLACK = 0

_spi = busio.SPI(board.SCK, board.MOSI, board.MISO)
_ecs  = digitalio.DigitalInOut(get_board_pin(13))
_dc   = digitalio.DigitalInOut(get_board_pin(12))
_rst  = digitalio.DigitalInOut(get_board_pin(9))
_busy = digitalio.DigitalInOut(get_board_pin(6))

# native panel dims are (122, 250); rotation=1 gives landscape 250x122
_display = Adafruit_SSD1680(122, 250, _spi,
    cs_pin=_ecs, dc_pin=_dc, sramcs_pin=None, rst_pin=_rst, busy_pin=_busy)

_display.rotation = 3

class EPDCompatibilityWrapper:
    def __init__(self, display_obj):
        self.display = display_obj
        self.width = display_obj.width
        self.height = display_obj.height
        self.y_off = 10      # set to 8 or -8 if the image is shifted vertically
        self.x_off = 0      # set to 8 or -8 if shifted horizontally

    def init(self):
        pass

    def clear(self, color=None):
        self.display.fill(Adafruit_EPD.WHITE)

    def show_string(self, text, x, y):
        self.display.text(text, x + self.x_off, y + self.y_off, Adafruit_EPD.BLACK)

    def draw_rectangle(self, x1, y1, x2, y2):
        x, y = min(x1, x2) + self.x_off, min(y1, y2) + self.y_off
        w, h = max(1, abs(x2 - x1)), max(1, abs(y2 - y1))
        self.display.rect(x, y, w, h, Adafruit_EPD.BLACK)

    def draw_line(self, x1, y1, x2, y2):
        self.display.line(x1 + self.x_off, y1 + self.y_off,
                          x2 + self.x_off, y2 + self.y_off, Adafruit_EPD.BLACK)

    def show_bitmap(self, bitmap, x, y):
        if not bitmap or not bitmap[0]:
            return
        for row_i, row in enumerate(bitmap):
            for col_i, pixel in enumerate(row):
                if pixel:
                    self.display.pixel(x + col_i + self.x_off,
                                       y + row_i + self.y_off, Adafruit_EPD.BLACK)

    def update(self):
        self.display.display()

epd = EPDCompatibilityWrapper(_display)
epd.clear(Color.WHITE)

# _____________________________________ Voice to Text _____________________________________
mic_adc = analogio.AnalogIn(board.A1)
SAMPLE_RATE = 16000 
FILENAME = "recording.wav" 

def write_wav_header(file, num_samples):
    file.write(b"RIFF")
    file.write((36 + num_samples).to_bytes(4, "little"))
    file.write(b"WAVEfmt ")
    file.write((16).to_bytes(4, "little"))
    file.write((1).to_bytes(2, "little"))      
    file.write((1).to_bytes(2, "little"))      
    file.write(SAMPLE_RATE.to_bytes(4, "little"))
    file.write((SAMPLE_RATE * 2).to_bytes(4, "little"))
    file.write((2).to_bytes(2, "little"))      
    file.write((16).to_bytes(2, "little"))     
    file.write(b"data")
    file.write(num_samples.to_bytes(4, "little"))

def collect_audio(samples):
    raw = mic_adc.value >> 4          
    samples.append(raw.to_bytes(2, "little"))
    time.sleep(0.000125)   
    return samples

#_________________________________Entering Text__________________________________________
def text_entry(prompt="Enter text:"):
    """
    Manual text entry using buttons (fallback for voice).
      up / down  = scroll through characters
      select     = commit the current character
      record     = tap: backspace (delete last committed char)
                   hold ~1s: exit typing, returns what's typed so far
      send_mes   = done, returns the string
    Only refreshes the e-ink when something actually changes.
    """
    charset = list("ABCDEFGHIJKLMNOPQRSTUVWXYZ0123456789 ")  # space at end
    idx = 0
    text = ""
    dirty = True   # redraw needed

    while True:
        if dirty:
            epd.clear(Color.WHITE)
            wrap_text(epd, prompt, 6, 4)
            # show the string being built
            shown = text if text else "_"
            wrap_text(epd, shown, 6, 30)
            # show the current character choice, marked
            cur = charset[idx]
            label_cur = "[space]" if cur == " " else cur
            epd.show_string("Char: " + label_cur, 6, 60)
            epd.show_string("sel=add rec=del send=done", 6, 90)
            epd.show_string("hold rec=exit", 6, 104)
            epd.update()
            dirty = False

        if up.value() == 0:
            idx = (idx + 1) % len(charset)
            dirty = True
            time.sleep(0.2)
        elif down.value() == 0:
            idx = (idx - 1) % len(charset)
            dirty = True
            time.sleep(0.2)
        elif select_button.value() == 0:
            text += charset[idx]
            dirty = True
            time.sleep(0.25)
        elif record_button.value() == 0:
            # Tap = backspace. Hold ~1s = exit typing and return what's typed.
            press_start = time.time()
            held_long = False
            while record_button.value() == 0:
                if time.time() - press_start >= 1.0:
                    held_long = True
                    break
                time.sleep(0.02)
            if held_long:
                # wait for release so the hold isn't re-read by the caller
                while record_button.value() == 0:
                    time.sleep(0.02)
                time.sleep(0.2)
                return text
            text = text[:-1]      # short tap = backspace
            dirty = True
            time.sleep(0.15)
        elif send_mes_button.value() == 0:
            time.sleep(0.25)
            return text
        else:
            machine.idle()

def record_or_type(dev_id=None, type_prompt="Type your response:", timeout=60):
    """
    Waits at a record/type prompt. If the user presses 'record', it records
    audio and returns the transcribed text (same behaviour as before). If the
    user presses 'up', it opens text_entry() and returns the typed string.
    Returns "" if nothing was entered within the timeout.
    """
    now_time = time.time()
    while time.time() - now_time < timeout:
        if record_button.value() == 0:
            samples = []
            while record_button.value() == 0:
                samples = collect_audio(samples)
            with open(FILENAME, "wb") as f:
                write_wav_header(f, len(samples) * 2)
                for s in samples:
                    f.write(s)
            return request_n_parse_translation(dev_id)
        elif up.value() == 0:
            time.sleep(0.2)
            return text_entry(type_prompt)
        machine.idle()
    return ""

# ____________________________Network & Request Compatibility ___________________________
class WLANCompatibility:
    class WLAN:
        IF_STA = 1  # Standard MicroPython constant
        
        def __init__(self, interface_id):
            pass
            
        def isconnected(self):
            # Explicitly import wifi to ensure we hit the global CircuitPython module
            import wifi
            return wifi.radio.connected
            
        def active(self, state):
            pass
            
        def connect(self, ssid, password):
            import wifi
            wifi.radio.connect(ssid, password)

pool = socketpool.SocketPool(wifi.radio)
ssl_context = ssl.create_default_context()

ssl_context.check_hostname = False

_requests_session = requests.Session(pool, ssl_context)
network = WLANCompatibility()

class UrequestsWrapper:
    def _with_retry(self, fn, retries=4, backoff=1.5):
        last = None
        for attempt in range(retries):
            try:
                return fn()
            except (OSError, RuntimeError) as e:
                last = e
                print(f"HTTP attempt {attempt + 1}/{retries} failed: {e}")
                # Free any half-open/stuck sockets before trying again
                try:
                    adafruit_connection_manager.connection_manager_close_all(pool)
                except Exception:
                    pass
                time.sleep(backoff * (attempt + 1))
        raise last

    def post(self, url, data=None, json=None, files=None, headers=None, **kwargs):
        if headers is None:
            headers = {}
        headers["X-Auth"] = DEVICE_TOKEN

        if files:
            boundary = f"----CPBoundary{random.randint(100000, 999999)}"
            body = bytearray()
            if isinstance(data, dict):
                for k, v in data.items():
                    body.extend(f"--{boundary}\r\nContent-Disposition: form-data; name=\"{k}\"\r\n\r\n{v}\r\n".encode())
            for field, file_obj in files.items():
                body.extend(f"--{boundary}\r\nContent-Disposition: form-data; name=\"{field}\"; filename=\"recording.wav\"\r\nContent-Type: audio/wav\r\n\r\n".encode())
                body.extend(file_obj.read())
                body.extend(b"\r\n")
            body.extend(f"--{boundary}--\r\n".encode())
            headers["Content-Type"] = f"multipart/form-data; boundary={boundary}"
            frozen = bytes(body)
            return self._with_retry(lambda: _requests_session.post(url, data=frozen, headers=headers, **kwargs))
        return self._with_retry(lambda: _requests_session.post(url, data=data, json=json, headers=headers, **kwargs))

    def get(self, url, **kwargs):
        headers = kwargs.pop("headers", {}) or {}
        headers["X-Auth"] = DEVICE_TOKEN
        return self._with_retry(lambda: _requests_session.get(url, headers=headers, **kwargs))
    
urequests = UrequestsWrapper()

def req_update(request, device_id=None):
    """
    This allows the device to request updates from the server.
    Using this, the device can check for new messages
    """
    r = urequests.get(f"{BASE_URL}/updates?Request={request}&dev_id={device_id}")
    data = r.json()

    return data

def request_n_parse_translation(dev_id=None):
    url = f"{BASE_URL}/stt"
    with open("recording.wav", "rb") as f:
        r = urequests.post(url, files={"file": f},
                           data={"Request": "transl", "ID": dev_id},
                           headers={"X-Auth": DEVICE_TOKEN})
    print("STT status:", r.status_code)
    print("STT body:", r.text[:200])
    if r.status_code != 200:
        return ""
    try:
        data = json.loads(r.text)
    except ValueError:
        return ""
    return data.get("text", "")

def encrypt_audio(pub_key, data: bytes) -> str:
    key = os.urandom(32)
    key_as_int = int.from_bytes(key, "big")
    encrypted_key = ce.encrypt_audio_key(pub_key, key_as_int)
    cipher = bytes(b ^ key[i % len(key)] for i, b in enumerate(data))
    combined = encrypted_key + cipher
    return binascii.b2a_base64(combined).decode("utf-8").strip()

def decrypt_audio(priv_key, encoded: str) -> bytes:
    d, n = priv_key
    key_size = (n.bit_length() + 7) // 8
    combined = binascii.a2b_base64(encoded)
    encrypted_key_bytes = combined[:key_size]
    cipher = combined[key_size:]
    encrypted_key_int = int.from_bytes(encrypted_key_bytes, "big")
    key_int = pow(encrypted_key_int, d, n)
    key = key_int.to_bytes(32, "big")
    return bytes(b ^ key[i % len(key)] for i, b in enumerate(cipher))

def play_pcm(pcm_data: bytes, sample_rate=8000, percent_vol=1):
    delay_s = 1.0 / sample_rate
    percent_vol = max(0, min(1, percent_vol))
    for i in range(0, len(pcm_data) - 1, 2):
        raw_sample = int.from_bytes(pcm_data[i:i+2], "little")
        sample_8 = raw_sample >> 4
        deviation = sample_8 - 128
        scaled_deviation = int(deviation * percent_vol)
        final_sample = 128 + scaled_deviation
        pwm_speaker.duty_cycle = int(final_sample * 256)
        time.sleep(delay_s)
    pwm_speaker.duty_cycle = 0

# ______________________________________ Machine Stubs ______________________________________
class MachineMock:
    WAKEUP_ANY_HIGH = 1
    WAKEUP_ALL_LOW = 0
    def idle(self): time.sleep(0.001)
    def deepsleep(self):
        import microcontroller
        microcontroller.reset()
    def pin_sleep_wakeup(self, pins, mode):
        # Real CircuitPython deep sleep: wake when the button is pressed.
        try:
            import alarm
            triggers = []
            for p in pins:
                raw = getattr(p, "_raw_pin", None)
                pull_up = getattr(p, "_pull_up", True)
                if raw is not None:
                    p.release()  # free the DigitalInOut so the alarm can claim the pin
                    # pull-up button reads low when pressed -> wake on value=False
                    wake_value = False if pull_up else True
                    triggers.append(alarm.pin.PinAlarm(pin=raw, value=wake_value, pull=True))
            if triggers:
                alarm.exit_and_deep_sleep_until_alarms(*triggers)
        except Exception:
            import microcontroller
            microcontroller.reset()
machine = MachineMock()
#_____________________________________Processing_________________________________________

FILLER_WORDS = ["uhh", "umm", "hmm", "uh,", "um", "hm"]
def processing(converted_text, del_words=FILLER_WORDS):
    """
    This function processes all voice-to-text
    in order to reove filler words (the list FILLER_WORDS)
    """

    words = converted_text.split()

    clean_words = [w for w in words if w not in del_words] #Makes a new list of words not including the filler words present
        
    processed_words = " ".join(clean_words) #Rejoins the list of words into a string
    return processed_words
    
#_____________________________________Networking + Encryption_________________________________________
LETTERS = ["a","b","c","d","e","f","g","h","i","j","k","l","m","n","o","p","q","r","s","t","u","v","w","x","y","z"," ",
    "A","B","C","D","E","F","G","H","I","J","K","L","M","N","O","P","Q","R","S","T","U","V","W","X","Y","Z",".",
    ",","/","[","]","`","~","\\","1","2","3","4","5","6","7","8","9","0","-","+","=","!","@","#","$","%","^","&",
    "*","(",")","<",">","?","|",";",";",":","'","\"","{","}"]

NUMBER_WORDS = {
    "zero": "0", "one": "1", "two": "2", "three": "3", "four": "4",
    "five": "5", "six": "6", "seven": "7", "eight": "8", "nine": "9",
    "ten": "10", "eleven": "11", "twelve": "12", "thirteen": "13",
    "fourteen": "14", "fifteen": "15", "sixteen": "16", "seventeen": "17",
    "eighteen": "18", "nineteen": "19", "twenty": "20", "thirty": "30",
    "forty": "40", "fifty": "50", "sixty": "60", "seventy": "70",
    "eighty": "80", "ninety": "90"
}
DIGIT_WORDS = {v: k for k, v in NUMBER_WORDS.items()}

def toggle_digit_word(word): #Changes from number to word-number form, vice versa
    lower = word.lower()
    if lower in NUMBER_WORDS:
        return NUMBER_WORDS[lower]
    elif word in DIGIT_WORDS:
        return DIGIT_WORDS[word]
    else:
        return word 


def confirm_wifi_password(raw_text):
    """
    This is a function for confirming the wifi password
    so I don't have to keep writing this code.

    The user can edit the wifi-password that was 
    received from voice-to-text
    """
    words = raw_text.split()
    word_index = 0

    while word_index < len(words):
        word = words[word_index]
        char_index = 0
        chars = list(word)
        while char_index < len(chars):
            epd.clear(Color.WHITE)
            current_word = "".join(chars)

            #Instructions for editing the password
            epd.show_string(f"Password so far: {' '.join(words[:word_index] + [current_word])}", 5, 5)
            epd.show_string(f"Editing letter '{chars[char_index]}' in word '{word}'", 5, 13)
            epd.show_string("Up = uppercase, Down = lowercase, Select = next letter", 5, 20)
            epd.show_string("Press Send to toggle this whole word digit/word form", 5, 27)
            percent = get_percent()
            draw_battery(epd, percent, epd.width - 40, 5)
            epd.update()

            #Button code for password editing
            if up.value() == 0:
                chars[char_index] = chars[char_index].upper()
                time.sleep(0.2)
            elif down.value() == 0:
                chars[char_index] = chars[char_index].lower()
                time.sleep(0.2)
            elif select_button.value() == 0:
                char_index += 1
                time.sleep(0.2)
            elif send_mes_button.value() == 0:
                toggled = toggle_digit_word("".join(chars))
                chars = list(toggled)
                char_index = min(char_index, len(chars) - 1) if chars else 0
                time.sleep(0.2)

        words[word_index] = "".join(chars) #Joins characters into a word
        word_index = word_index + 1

    final_password = "".join(words) #Joins words into final password string
    return final_password
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

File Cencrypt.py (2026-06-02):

import random

LETTERS = ["a","b","c","d","e","f","g","h","i","j","k","l","m","n","o","p","q","r","s","t","u","v","w","x","y","z"," ",
    "A","B","C","D","E","F","G","H","I","J","K","L","M","N","O","P","Q","R","S","T","U","V","W","X","Y","Z",".",
    ",","/","[","]","`","~","\\","1","2","3","4","5","6","7","8","9","0","-","+","=","!","@","#","$","%","^","&",
    "*","(",")","<",">","?","|",";",";",":","'","\"","{","}"]

# ------------------ FIXED: index_find uses the correct alphabet ------------------
def index_find(key, alphabet):
    for idx, char in enumerate(alphabet):
        if char == key:
            return idx
    return -1

# ------------------ FIXED: cipher always uses the passed alphabet ------------------
def cipher(message, alphabet=LETTERS):
    if not message:
        return "", alphabet[0]

    # pick a random character from the message as the key
    num = random.randint(0, len(message) - 1)
    key = message[num]
    j = index_find(key, alphabet)

    # convert message to indexes
    split_letters = [index_find(c, alphabet) for c in message]

    # shift indexes
    for i in range(len(split_letters)):
        split_letters[i] = (split_letters[i] + j) % len(alphabet)

    # convert back to characters
    new_message = "".join(alphabet[i] for i in split_letters)

    # send the key character (alphabet[j])
    sent_key = alphabet[j]

    return new_message, sent_key

# ------------------ FIXED: decipher always uses the passed alphabet ------------------
def decipher(message, alphabet=LETTERS):
    if not message:
        return ""

    # first character is the key
    key = message[0]
    j = index_find(key, alphabet)

    # rest is the encrypted text
    cipher_text = message[1:]

    # convert to indexes
    split_ciphered = [index_find(c, alphabet) for c in cipher_text]

    # reverse the shift
    for i in range(len(split_ciphered)):
        split_ciphered[i] = (split_ciphered[i] - j) % len(alphabet)

    # convert back to characters
    deciphered_message = "".join(alphabet[i] for i in split_ciphered)

    return deciphered_message

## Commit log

2026-06-03 Enhance README with device functionality details
    Added detailed explanation of device functionality.
2026-06-05 Rename project from Handheld-Encryption-Device to Handcryption
2026-06-05 Reorganized the framework to fit logical flow
2026-06-05 Fixed the client logic and added in measures if the server closed, this still has many placeholders
    [Handheld Encryption.py]
2026-06-13 Added a UI - makes the device more practical
2026-06-13 Update ESP32 description to Adafruit ESP32-S2 Feather
2026-06-15 Rewrite README for cloud-based relay architecture
    Updated README to clarify features and device setup instructions.
2026-06-15 Added BOM for Handcryption project
    [Handcryption BOM - Sheet1.csv]
2026-06-16 Revise framework and process for VOSK and cloud integration
    Updated framework details and process flow.
2026-06-16 Update README with ngrok instructions and button roles - previous ngrok instructions included my domain
    Clarified ngrok usage and updated example URL.
2026-06-17 Update BOM with new items
    [Handcryption BOM - Sheet1 (1).csv]
2026-06-17 Added Wiring Schematics
2026-06-20 Add README for 3D-Models folder
    This README provides context for the 3D-Models folder, including notes on measurements and assembly.
2026-06-20 Add all 3d-Models to folder
    [Adafruit 2.13- Monochrome eInk - ePaper Display.stl, Adafruit ESP32-S2 Feather Board.stl, Adafruit STEMMA Speaker.stl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]
2026-06-22 Add .step files
    [Adafruit 2.13- Monochrome eInk - ePaper Display.step, Adafruit ESP32-S2 Feather Board.step, Adafruit STEMMA Speaker.step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]
2026-06-22 Add wiring diagram to README
    Added an image to the README file.
2026-07-09 Changed code from Micropython to Circuitpython
    Changed code from Micropython to Circuitpython for Easier Use of E-ink Display
2026-07-09 Revise README for CircuitPython transition and updates
    Updated project details to reflect the transition from MicroPython to CircuitPython, including changes to device specifications and server setup instructions.
